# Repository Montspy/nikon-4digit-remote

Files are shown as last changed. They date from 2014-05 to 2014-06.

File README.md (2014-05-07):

nikon-4digit-remote
===================

Nikon remote based on cheap 0-30V voltmeter bought on eBay
Based on the hack and code from Baoshi http://www.ba0sh1.com/hacking-a-cheap-led-voltmeter/

###Functionality
- Self-timer				(1->999s delay)
- Time-lapse mode			(1/2s->999s interval)
- Bulb mode
- 1s delayed bulb mode
- Programmable bulb mode 	(1->999s exposure time)

- 1Cell LiPo
- Auto-cutoff
- USB charging

###User interface
The user navigates through the menu with a simple potentiometer. 
- Cancel/Back: full turn to the left, back to the center posistion
- OK/Enter: full turn to the right, back to the center posistion
- Increment: small right turn, back to the center posistion
- Decrement: small left turn, back to the center posistion

The 4-digit display is divided in two zones:
- The first digit indicates the mode or menu you are in. Blinking if the mode is active (ie taking pictures).
- The 2nd, 3rd and 4th digits shows the delay/interval/exposure time in seconds.

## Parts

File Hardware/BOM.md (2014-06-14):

Bills of materials
==================

| Qty  | Item  | Price |
| ---: | :--- | ---: |
| 1 | STM8S003-based voltmeter | $6 |
| 1 | 1 Cell 300mAh-ish LiPo battery | $6 |
| 1 | 1 Cell LiPo USB charger | $2 |
| 1 | Nikon remote cable | $2.50 |
| 1 | 2.2k resistor |  |
| 1 | 10k-100k potentiometer |  |
|  | Small wires |  |
| **Total** |  | ~$16.50 |

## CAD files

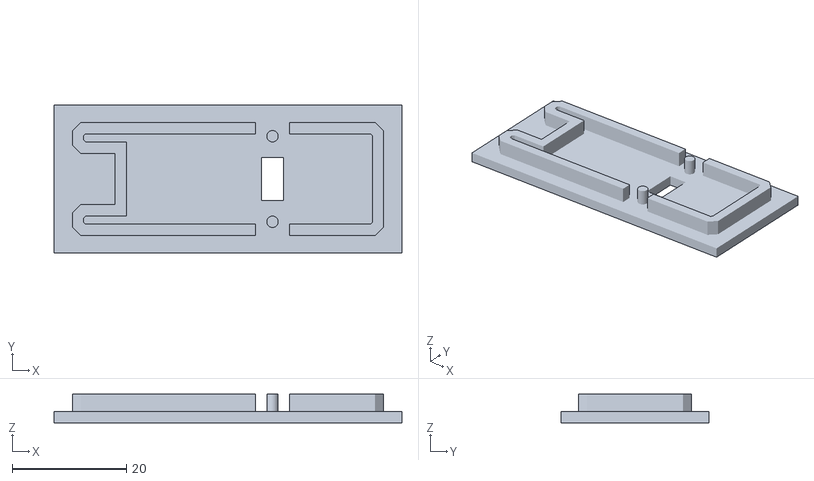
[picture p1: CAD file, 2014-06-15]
Hardware/Case/Case_bottom_with_switch.STL
61.0 x 26.0 x 5.00

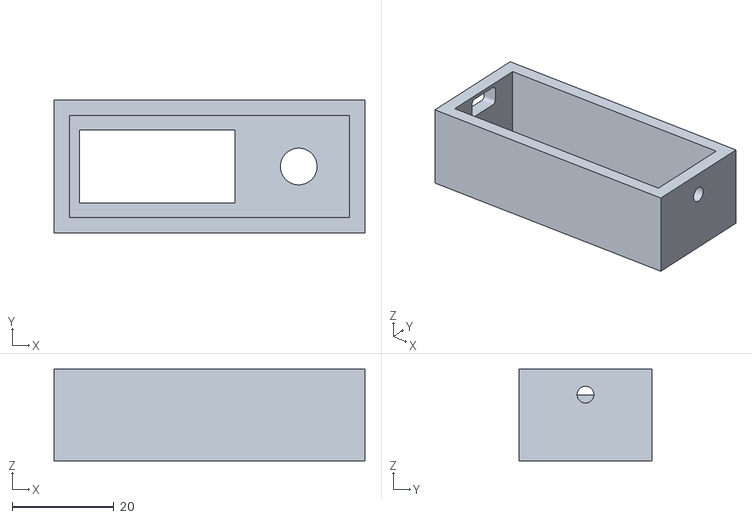
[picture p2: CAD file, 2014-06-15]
Hardware/Case/Case.STL
61.0 x 26.0 x 18.0

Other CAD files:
Hardware/Case/Case_bottom.STL

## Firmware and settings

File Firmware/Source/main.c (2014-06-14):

#include "stm8s.h"
#include "led.h"

#include "ihm.h"
#include "pot.h"
#include "shutter.h"

/**
  * @brief  Configure system clock 
  * @param  None
  * @retval None
  */
static void CLK_Config(void)
{
    CLK_DeInit();

    /* Configure the Fcpu to DIV1 */
    CLK_SYSCLKConfig(CLK_PRESCALER_CPUDIV1);
    
    /* Configure the HSI prescaler */
    CLK_SYSCLKConfig(CLK_PRESCALER_HSIDIV1);

    /* Output Fcpu on CLK_CCO pin */
    //CLK_CCOConfig(CLK_OUTPUT_CPU);
        
    /* Configure the system clock to use HSI clock source */
    CLK_ClockSwitchConfig(CLK_SWITCHMODE_AUTO, CLK_SOURCE_HSI, DISABLE, CLK_CURRENTCLOCKSTATE_DISABLE);
}

static void ITC_Config(void)
{
  ITC_SetSoftwarePriority(ITC_IRQ_ADC1, ITC_PRIORITYLEVEL_2); // POT timeout
  ITC_SetSoftwarePriority(ITC_IRQ_TIM2_CAPCOM, ITC_PRIORITYLEVEL_2); // POT timeout
  ITC_SetSoftwarePriority(ITC_IRQ_TIM1_OVF, ITC_PRIORITYLEVEL_1);    // LED main interrupt
  ITC_SetSoftwarePriority(ITC_IRQ_TIM1_CAPCOM, ITC_PRIORITYLEVEL_1); // LED dimming interrupt
}

void main( void )
{
  //CFG->GCR |= 0x01; /* disable SWIM to use PD1 as a standard I/O */ 
  CLK_Config();
  ITC_Config();
  led_init();
  pot_init();
  shutter_init();
  IHM_init();
  
  enableInterrupts();
  
  led_on();
  
  while (1)
  {
    wfi();
    pot_updateState();
    IHM_updateState();
  }
}

#ifdef USE_FULL_ASSERT

/**
  * @brief  Reports the name of the source file and the source line number
  *   where the assert_param error has occurred.
  * @param file: pointer to the source file name
  * @param line: assert_param error line source number
  * @retval : None
  */
void assert_failed(u8* file, u32 line)
{ 
  /* User can add his own implementation to report the file name and line number,
     ex: printf("Wrong parameters value: file %s on line %d\r\n", file, line) */

  /* Infinite loop */
  while (1)
  {
  }
}
#endif

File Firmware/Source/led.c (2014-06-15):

/*
# Copyright (c) 2013, Thomas S. Price
# All rights reserved.
#
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
# THIS SOFTWARE IS PROVIDED BY THE COPYRIGHT HOLDERS AND CONTRIBUTORS "AS IS" AND
# ANY EXPRESS OR IMPLIED WARRANTIES, INCLUDING, BUT NOT LIMITED TO, THE IMPLIED
# WARRANTIES OF MERCHANTABILITY AND FITNESS FOR A PARTICULAR PURPOSE ARE DISCLAIMED.
# IN NO EVENT SHALL THE COPYRIGHT HOLDER OR CONTRIBUTORS BE LIABLE FOR ANY DIRECT,
# INDIRECT, INCIDENTAL, SPECIAL, EXEMPLARY, OR CONSEQUENTIAL DAMAGES (INCLUDING,
# BUT NOT LIMITED TO, PROCUREMENT OF SUBSTITUTE GOODS OR SERVICES; LOSS OF USE,
# DATA, OR PROFITS; OR BUSINESS INTERRUPTION) HOWEVER CAUSED AND ON ANY THEORY OF
# LIABILITY, WHETHER IN CONTRACT, STRICT LIABILITY, OR TORT (INCLUDING NEGLIGENCE
# OR OTHERWISE) ARISING IN ANY WAY OUT OF THE USE OF THIS SOFTWARE, EVEN IF ADVISED
# OF THE POSSIBILITY OF SUCH DAMAGE.
*/
#include "stm8s.h"
#include "led.h"
#include "ihm.h"

#define DEFAULT_LED_DUTY 10


static char _display_buf[4] = {0};

static uint8_t _duty;

static led_blink_type _blink;
static led_blink_mode _blink_mode;

static void _led_write_segments(char ch)
{
  /* Character Map, segments active-low
*
*        0 1 2 3 4 5 6 7 8 9 A B C D E F L P T U
* A: PB5 0 1 0 0 1 0 0 0 0 0 0 1 0 1 0 0 1 0 1 1
* F: PA1 0 1 1 1 0 0 0 1 0 0 0 0 0 1 0 0 0 0 0 0
* B: PB4 0 0 0 0 0 1 1 0 0 0 0 1 1 0 1 1 1 0 1 0
* G: PC3 1 1 0 0 0 0 0 1 0 0 0 0 1 0 0 0 1 0 0 1
* C: PC4 0 0 1 0 0 0 0 0 0 0 0 0 1 0 1 1 1 1 1 0
* E: PC7 0 1 0 1 1 1 0 1 0 1 0 0 0 0 0 0 0 0 0 0
* D: PC6 0 1 0 0 1 0 0 1 0 0 1 0 0 0 0 1 0 1 0 0
*/
  switch (ch & 0x7f)
  {
  case 0: // 0
    GPIO_WriteLow(GPIOA, (GPIO_Pin_TypeDef)(GPIO_PIN_1));
    GPIO_WriteLow(GPIOB, (GPIO_Pin_TypeDef)(GPIO_PIN_4 | GPIO_PIN_5));
    GPIO_WriteLow(GPIOC, (GPIO_Pin_TypeDef)(GPIO_PIN_4 | GPIO_PIN_6 | GPIO_PIN_7));
    GPIO_WriteHigh(GPIOC, (GPIO_Pin_TypeDef)(GPIO_PIN_3));
    break;
  case 1: // 1
    GPIO_WriteHigh(GPIOA, (GPIO_Pin_TypeDef)(GPIO_PIN_1));
    GPIO_WriteLow(GPIOB, (GPIO_Pin_TypeDef)(GPIO_PIN_4));
    GPIO_WriteHigh(GPIOB, (GPIO_Pin_TypeDef)(GPIO_PIN_5));
    GPIO_WriteLow(GPIOC, (GPIO_Pin_TypeDef)(GPIO_PIN_4));
    GPIO_WriteHigh(GPIOC, (GPIO_Pin_TypeDef)(GPIO_PIN_3 | GPIO_PIN_6 | GPIO_PIN_7));
    break;
  case 2: // 2
    GPIO_WriteHigh(GPIOA, (GPIO_Pin_TypeDef)(GPIO_PIN_1));
    GPIO_WriteLow(GPIOB, (GPIO_Pin_TypeDef)(GPIO_PIN_4 | GPIO_PIN_5));
    GPIO_WriteLow(GPIOC, (GPIO_Pin_TypeDef)(GPIO_PIN_3 | GPIO_PIN_6 | GPIO_PIN_7));
    GPIO_WriteHigh(GPIOC, (GPIO_Pin_TypeDef)(GPIO_PIN_4));
    break;
  case 3: // 3
    GPIO_WriteHigh(GPIOA, (GPIO_Pin_TypeDef)(GPIO_PIN_1));
    GPIO_WriteLow(GPIOB, (GPIO_Pin_TypeDef)(GPIO_PIN_4 | GPIO_PIN_5));
    GPIO_WriteLow(GPIOC, (GPIO_Pin_TypeDef)(GPIO_PIN_3 | GPIO_PIN_4 | GPIO_PIN_6));
    GPIO_WriteHigh(GPIOC, (GPIO_Pin_TypeDef)(GPIO_PIN_7));
    break;
  case 4: // 4
    GPIO_WriteLow(GPIOA, (GPIO_Pin_TypeDef)(GPIO_PIN_1));
    GPIO_WriteLow(GPIOB, (GPIO_Pin_TypeDef)(GPIO_PIN_4));
    GPIO_WriteHigh(GPIOB, (GPIO_Pin_TypeDef)(GPIO_PIN_5));
    GPIO_WriteLow(GPIOC, (GPIO_Pin_TypeDef)(GPIO_PIN_3 | GPIO_PIN_4));
    GPIO_WriteHigh(GPIOC, (GPIO_Pin_TypeDef)(GPIO_PIN_6 | GPIO_PIN_7));
    break;
  case 5: // 5
    GPIO_WriteLow(GPIOA, (GPIO_Pin_TypeDef)(GPIO_PIN_1));
    GPIO_WriteLow(GPIOB, (GPIO_Pin_TypeDef)(GPIO_PIN_5));
    GPIO_WriteHigh(GPIOB, (GPIO_Pin_TypeDef)(GPIO_PIN_4));
    GPIO_WriteLow(GPIOC, (GPIO_Pin_TypeDef)(GPIO_PIN_3 | GPIO_PIN_4 | GPIO_PIN_6));
    GPIO_WriteHigh(GPIOC, (GPIO_Pin_TypeDef)(GPIO_PIN_7));
    break;
  case 6: // 6
    GPIO_WriteLow(GPIOA, (GPIO_Pin_TypeDef)(GPIO_PIN_1));
    GPIO_WriteLow(GPIOB, (GPIO_Pin_TypeDef)(GPIO_PIN_5));
    GPIO_WriteHigh(GPIOB, (GPIO_Pin_TypeDef)(GPIO_PIN_4));
    GPIO_WriteLow(GPIOC, (GPIO_Pin_TypeDef)(GPIO_PIN_3 | GPIO_PIN_4 | GPIO_PIN_6 | GPIO_PIN_7));
    break;
  case 7: // 7
    GPIO_WriteHigh(GPIOA, (GPIO_Pin_TypeDef)(GPIO_PIN_1));
    GPIO_WriteLow(GPIOB, (GPIO_Pin_TypeDef)(GPIO_PIN_4 | GPIO_PIN_5));
    GPIO_WriteLow(GPIOC, (GPIO_Pin_TypeDef)(GPIO_PIN_4));
    GPIO_WriteHigh(GPIOC, (GPIO_Pin_TypeDef)(GPIO_PIN_3 | GPIO_PIN_6 | GPIO_PIN_7));
    break;
  case 8: // 8
    GPIO_WriteLow(GPIOA, (GPIO_Pin_TypeDef)(GPIO_PIN_1));
    GPIO_WriteLow(GPIOB, (GPIO_Pin_TypeDef)(GPIO_PIN_4 | GPIO_PIN_5));
    GPIO_WriteLow(GPIOC, (GPIO_Pin_TypeDef)(GPIO_PIN_3 | GPIO_PIN_4 | GPIO_PIN_6 | GPIO_PIN_7));
    break;
  case 9: // 9
    GPIO_WriteLow(GPIOA, (GPIO_Pin_TypeDef)(GPIO_PIN_1));
    GPIO_WriteLow(GPIOB, (GPIO_Pin_TypeDef)(GPIO_PIN_4 | GPIO_PIN_5));
    GPIO_WriteLow(GPIOC, (GPIO_Pin_TypeDef)(GPIO_PIN_3 | GPIO_PIN_4 | GPIO_PIN_6));
    GPIO_WriteHigh(GPIOC, (GPIO_Pin_TypeDef)(GPIO_PIN_7));
    break;
  case 10: // A
    GPIO_WriteLow(GPIOA, (GPIO_Pin_TypeDef)(GPIO_PIN_1));
    GPIO_WriteLow(GPIOB, (GPIO_Pin_TypeDef)(GPIO_PIN_4 | GPIO_PIN_5));
    GPIO_WriteLow(GPIOC, (GPIO_Pin_TypeDef)(GPIO_PIN_3 | GPIO_PIN_4 | GPIO_PIN_7));
    GPIO_WriteHigh(GPIOC, (GPIO_Pin_TypeDef)(GPIO_PIN_6));
    break;
  case 11: // B
    GPIO_WriteLow(GPIOA, (GPIO_Pin_TypeDef)(GPIO_PIN_1));
    GPIO_WriteHigh(GPIOB, (GPIO_Pin_TypeDef)(GPIO_PIN_4 | GPIO_PIN_5));
    GPIO_WriteLow(GPIOC, (GPIO_Pin_TypeDef)(GPIO_PIN_3 | GPIO_PIN_4 | GPIO_PIN_6 | GPIO_PIN_7));
    break;
  case 12: // C
    GPIO_WriteLow(GPIOA, (GPIO_Pin_TypeDef)(GPIO_PIN_1));
    GPIO_WriteLow(GPIOB, (GPIO_Pin_TypeDef)(GPIO_PIN_5));
    GPIO_WriteHigh(GPIOB, (GPIO_Pin_TypeDef)(GPIO_PIN_4));
    GPIO_WriteLow(GPIOC, (GPIO_Pin_TypeDef)(GPIO_PIN_6 | GPIO_PIN_7));
    GPIO_WriteHigh(GPIOC, (GPIO_Pin_TypeDef)(GPIO_PIN_3 | GPIO_PIN_4));
    break;
  case 13: // D
    GPIO_WriteHigh(GPIOA, (GPIO_Pin_TypeDef)(GPIO_PIN_1));
    GPIO_WriteLow(GPIOB, (GPIO_Pin_TypeDef)(GPIO_PIN_4));
    GPIO_WriteHigh(GPIOB, (GPIO_Pin_TypeDef)(GPIO_PIN_5));
    GPIO_WriteLow(GPIOC, (GPIO_Pin_TypeDef)(GPIO_PIN_3 | GPIO_PIN_4 | GPIO_PIN_6 | GPIO_PIN_7));
    break;
  case 14: // E
    GPIO_WriteLow(GPIOA, (GPIO_Pin_TypeDef)(GPIO_PIN_1));
    GPIO_WriteLow(GPIOB, (GPIO_Pin_TypeDef)(GPIO_PIN_5));
    GPIO_WriteHigh(GPIOB, (GPIO_Pin_TypeDef)(GPIO_PIN_4));
    GPIO_WriteLow(GPIOC, (GPIO_Pin_TypeDef)(GPIO_PIN_3 | GPIO_PIN_6 | GPIO_PIN_7));
    GPIO_WriteHigh(GPIOC, (GPIO_Pin_TypeDef)(GPIO_PIN_4));
    break;
  case 15: // F
    GPIO_WriteLow(GPIOA, (GPIO_Pin_TypeDef)(GPIO_PIN_1));
    GPIO_WriteLow(GPIOB, (GPIO_Pin_TypeDef)(GPIO_PIN_5));
    GPIO_WriteHigh(GPIOB, (GPIO_Pin_TypeDef)(GPIO_PIN_4));
    GPIO_WriteLow(GPIOC, (GPIO_Pin_TypeDef)(GPIO_PIN_3 | GPIO_PIN_7));
    GPIO_WriteHigh(GPIOC, (GPIO_Pin_TypeDef)(GPIO_PIN_4 | GPIO_PIN_6));
    break;
  case LED_L: // L
    GPIO_WriteLow(GPIOA, (GPIO_Pin_TypeDef)(GPIO_PIN_1));
    GPIO_WriteHigh(GPIOB, (GPIO_Pin_TypeDef)(GPIO_PIN_4 | GPIO_PIN_5));
    GPIO_WriteHigh(GPIOC, (GPIO_Pin_TypeDef)(GPIO_PIN_3 | GPIO_PIN_4));
    GPIO_WriteLow(GPIOC, (GPIO_Pin_TypeDef)(GPIO_PIN_6 | GPIO_PIN_7));
    break;
  case LED_P: // P
    GPIO_WriteLow(GPIOA, (GPIO_Pin_TypeDef)(GPIO_PIN_1));
    GPIO_WriteLow(GPIOB, (GPIO_Pin_TypeDef)(GPIO_PIN_4 | GPIO_PIN_5));
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

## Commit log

2014-05-07 Added bills of material
2014-05-07 BOM updated
2014-05-07 BOM rectified
2014-05-09 Added pot.c/h: Potentiometer statechart TODO: ADC TODO: pot timer
    Added ihm.c/h
    Menu statechart
    TODO: activated mode cases
    TODO: IHM timer
2014-05-10 added shutter.c/h files. Shutter cable HAL.
2014-05-10 Added shutter.c/h to the project file. Modified ihm.c/h - Now displays menu on 4-digit display - blink at 1Hz when selected - blink at 2Hz when active Modified led.c/h - Added led_set_number method t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
    [ihm.c, ihm.h, led.c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]
2014-06-14 new gitignore and BOM
2014-06-14 Added STL files for the 3D printed case. Working firmware in beta.
    [Case.STL, Case_bottom.STL]
2014-06-15 Adjusted STL files dimensions for a better fit
    [Case.STL, Case_bottom.STL]
2014-06-15 Added a bottom case with a switch hole
    [Case_bottom_with_switch.STL]
